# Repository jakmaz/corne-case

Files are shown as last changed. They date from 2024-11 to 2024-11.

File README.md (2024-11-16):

# Wireless 6 Column Choc Corne Case

This case is modeled for the low-profile choc-spaced PCB from Typeractive. It includes both solid and cutout covers for the display, providing flexibility based on your preferences. Additionally, I've included **tenting legs attached with magnets** for added comfort and flexibility.

## Features

- **Sturdy design** with thicker walls
- Just thin enough for a standard USB-C connector to still fit through the wall
- **Very low profile** for a sleek look
- Tight tolerances for a clean and polished build
- Insets for screws on the bottom allow using the case without rubber feet if desired
- **Two cover options**: Solid or cutout for the display
- **Magnetic tenting legs** for ergonomic positioning
- **STL and Shapr3D files provided** for easy customization

---

## Future Plans

- Create a **traveling case** for portability and protection.
- Design a **case with a bigger battery** for extended usage.
- Develop an **aluminum CNC file** for a premium, durable build.

---

## Build Guide

For detailed assembly instructions, including required parts, printing tips, and step-by-step assembly, visit the **[Build Guide](./docs/build-guide.md)**.

---

## Firmware

The firmware configuration for this case is available in my repository:  
**[Corne ZMK Firmware Configuration](https://github.com/jakmaz/corne-zmk)**.

This includes the keymap and settings optimized for a wireless Corne keyboard build using ZMK.

---

## STL and Shapr3D Files

To make this case customizable, I’ve included both the **STL files** for 3D printing and the **Shapr3D files** if you want to edit the parts yourself.

---

## Credits

This project wouldn’t be possible without the inspiration and ideas from these sources:

- **[Felix's Corne Case](https://makerworld.com/en/models/518698#profileId-435003):** This was the main source for the case design and documentation.
- **[Forager Keyboard](https://github.com/carrefinho/forager/tree/main?tab=readme-ov-file):** The tenting leg design was inspired by this project.
- **[Typeractive](https://typeractive.xyz/):** Covers were exported from the typeractive 3D builder.

---

## Need Help?

If you have questions or need assistance, feel free to **[open an issue](../../issues)** in this repository or **[email me](mailto:jakmaz.dev@icloud.com)**.

Happy building!

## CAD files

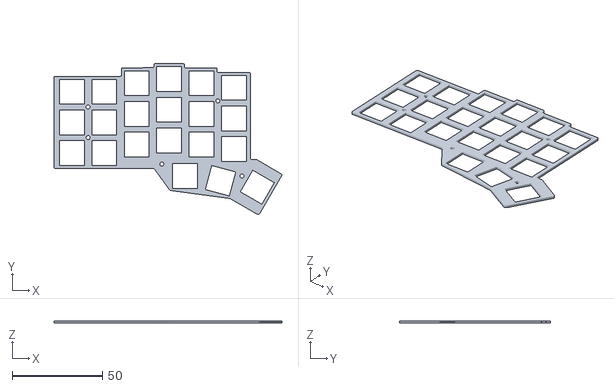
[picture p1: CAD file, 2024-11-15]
case/plate.stl
126.5 x 83.5 x 1.20

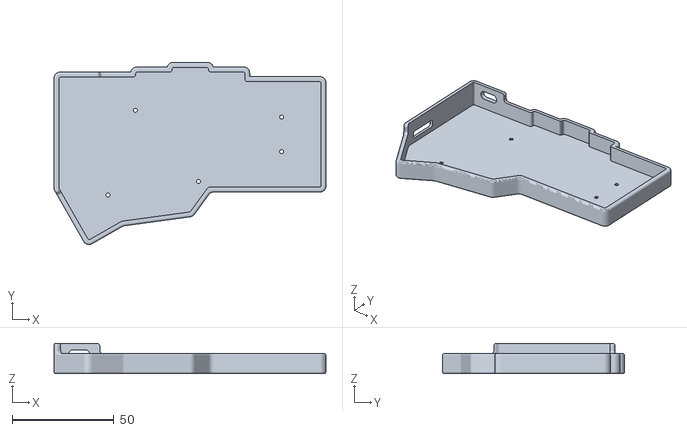
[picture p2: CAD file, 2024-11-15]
case/case-left.stl
133.8 x 89.6 x 15.0

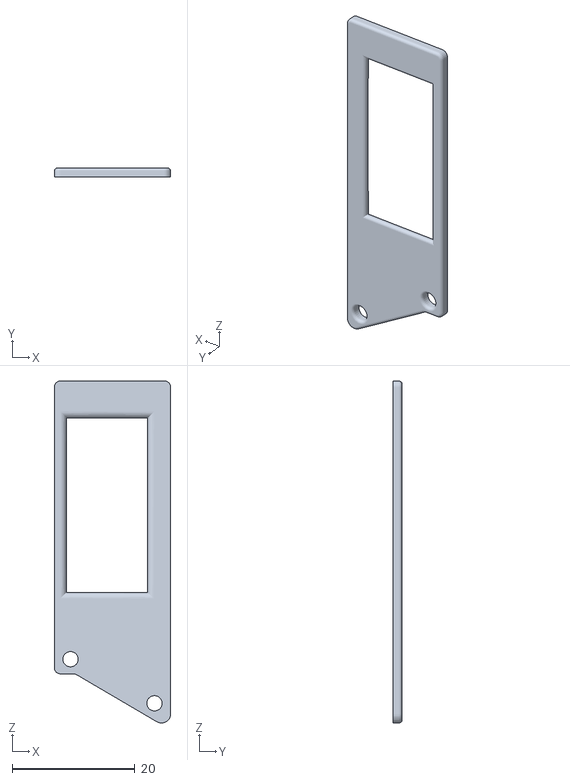
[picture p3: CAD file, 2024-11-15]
case/cover-cutout.stl
19.0 x 1.50 x 55.8

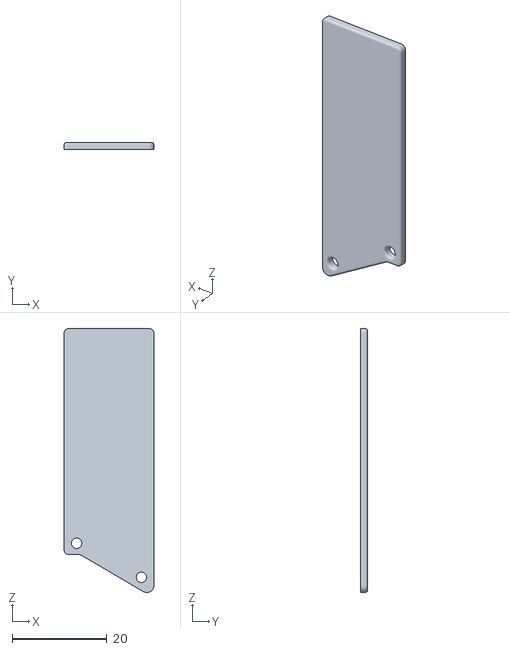
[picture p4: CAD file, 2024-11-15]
case/cover-solid.stl
19.0 x 1.50 x 55.8

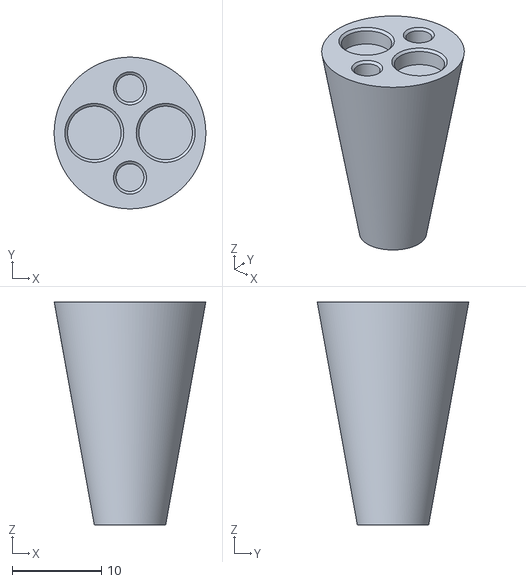
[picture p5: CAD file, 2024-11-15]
case/tenting-leg.stl
17.0 x 17.0 x 25.0

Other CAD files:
case/case-right.stl

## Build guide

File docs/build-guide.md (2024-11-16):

# Build Guide for the Wireless 6 Column Choc Corne Case

This guide provides step-by-step instructions to assemble your Corne keyboard case and components.

---

## What You Need

### Printed Parts

- **Plates:** [Download here](../case)
- **Cases:** [Download here](../case)
- **Covers:** [Solid](../case/cover-solid.stl) | [Cutout](../case/cover-cutout.stl)
- **Tenting Legs:** [Download here](../case/tenting-leg.stl)

**Printing Tips:**

- I printed everything in PLA with a 0.4mm nozzle at a 0.2mm layer height.
- To achieve a flawless print, I reduced the maximum material flow to 8mm³/s.
- For a weightier feel and better sound, I made the prints solid.
- If printing the covers with your own profile, use ironing for a perfect surface finish.

---

### Bought Parts

#### General

All the parts below can be easily bought on typeractive store

- **Typeractive choc-spaced 6 Column Corne PCB:** [Buy](https://typeractive.xyz/products/corne-partially-assembled-pcb)
- **42 Kailh Choc switches:** [Buy](https://typeractive.xyz/products/choc-switches)
- **42 Kailh Choc keycaps:** [Buy](https://typeractive.xyz/products/mbk-keycaps)
- **2 Nice!Nanos wireless microcontrollers:** [Buy](https://typeractive.xyz/products/nice-nano)
- **OPTIONAL: 2 Nice!Views displays:** [Buy](https://nicekeyboards.com/nice-view)

#### Screws and Standoffs

- 10x M2x3 screws with countersunk head (for the bottom of the case)
- 10x M2x4 female/female standoffs (for connecting the case and the plate through the PCB)
- 10x M2x3 screws with flat head (for the plate)
- **OPTIONAL:** 8x M2x3 screws with flat head or longer (for the optional display covers)
- **OPTIONAL:** 4x M2x10 female/female standoffs (for the optional display covers)

#### Miscellaneous

- Rubber feet (e.g., 3M bumpons)

**Note:** Slightly longer screws may still work if the exact sizes are unavailable.

---

## Assembly Steps

1. **Assemble/Solder the PCB**

   - Solder all components to your PCB according to the [documentation](https://docs.typeractive.xyz/build-guides/corne-wireless).

2. **Insert Switches**

   - Insert switches into the plate first, then into the PCB. Avoid attaching keycaps at this stage to prevent interference.

3. **Optional Steps**

   - If using the decorative covers, screw in the standoffs and attach the covers on top.
   - Attach the tenting legs using the built-in magnets for ergonomic positioning.

4. **Attach the PCB to the Case**

   - Screw the standoffs into the cases.
   - Drop the assembled PCBs into the cases onto the standoffs, making sure the switches align with the side cutouts.

5. **Secure the Plates**

   - Use the remaining screws to secure the plates to the case standoffs.

6. **Add Rubber Feet**

   - Glue some rubber feet to the bottom of the case for stability.

---

Happy building!

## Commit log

2024-11-15 🐣 Initial README.md
2024-11-15 📝 Add firmware and credits sections
2024-11-15 ✨ Tenting leg
    [tenting-leg.stl]
2024-11-15 📝 Split readme to main page and build guide
2024-11-15 ✨ Case elements
    [case-left.stl, case-right.stl, cover-cutout.stl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]
2024-11-15 🐣 Initial Commit
2024-11-15 📝 Add typeractive credit
2024-11-16 📝 Links update
2024-11-16 📝 Add future plans
